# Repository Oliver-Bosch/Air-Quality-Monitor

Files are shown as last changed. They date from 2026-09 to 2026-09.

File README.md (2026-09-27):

# Air-Quality-Monitor

This is a guide to build your own Air-Quality-Monitor (**AQM**). The AQM measures CO2, relative humidity, temperature and particulate matter. The current readings are displayed on a 4-inch TFT screen. The device is connected to the local network via Wi-Fi to synchronise time.

<p align="center">
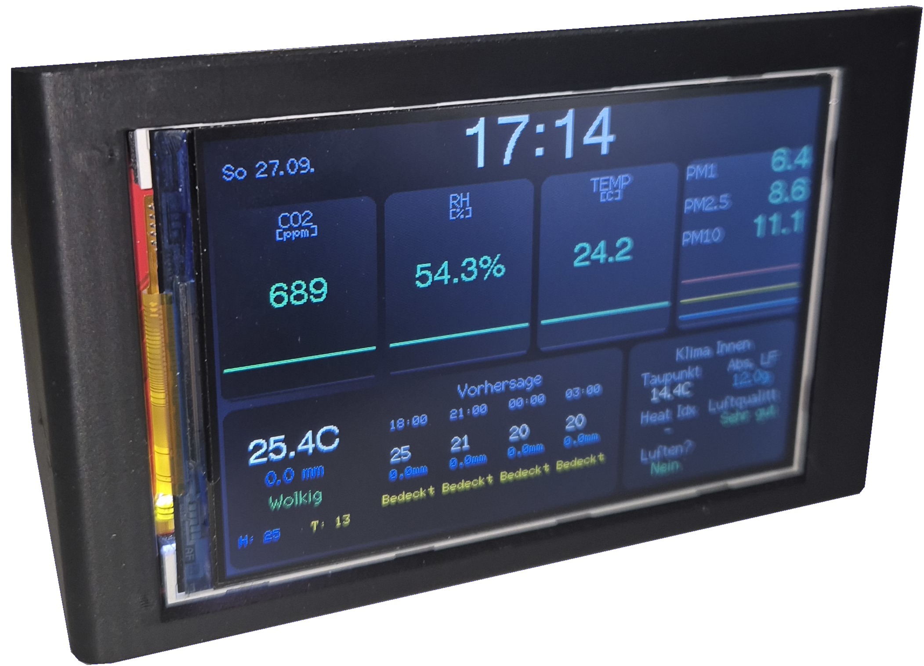
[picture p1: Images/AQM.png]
Image of the AQM
  
</p>

# Table of Contents

- [Parts](#parts)
- [Assembly](#assembly)
- [Installation](#installation)
- [Settings](#settings)
- [Price](#price)
- [Notes](#notes)

# Parts

- ESP32S
- SCD41 CO₂ Sensor
- SHT40 Temperature & Humidity Sensor
- SPS30 Particulate Matter Sensor
- VEML7700 Ambient Light Sensor
- ILI9488 4 Inch TFT Display

# Assembly

To assembel the AQM you should first start with testing all the components on a bredboard which are connected as in figure X. After checking the functinality of all components and printing the body of the case you start by soldering the components to each other as shown in figure Y. Start with screwing the TFT display in place (depending on screw length you have to use washers/springs). After that place the SPS30 in the lower corner with the connector facing the dividing wall of the case. Then you can screw in the SHT40 into its respectiv mounting holes. The SCD41 is mounted using a wedge because of the missing mounting holes. At last step mount the VEML7700 with the pins facing inside and then close the lid of the AQM.

# Installation

After wiring up all components you just need to download the Code and flash it to the ESP32 using the Arduino IDE or similar programms. 

# Settings

All different settings can be changed in the "config.h" file. 

# Price

<div align="center">

| Part | Price |
|---|---|
| ESP32S | 3,42 € |
| SCD41  | 17,99 € |
| SHT40  | 2,79 € |
| SPS30  | 10,45 € |
| VEML7700 | 1,66 € |
| ILI9488 4" TFT Display | 13,52 € |
| **Total** | **49.68 €** |

\* All parts sourced on Aliexpress Mai 2026

<div align="left">

# Notes

Future Home Assistant integration is planned.

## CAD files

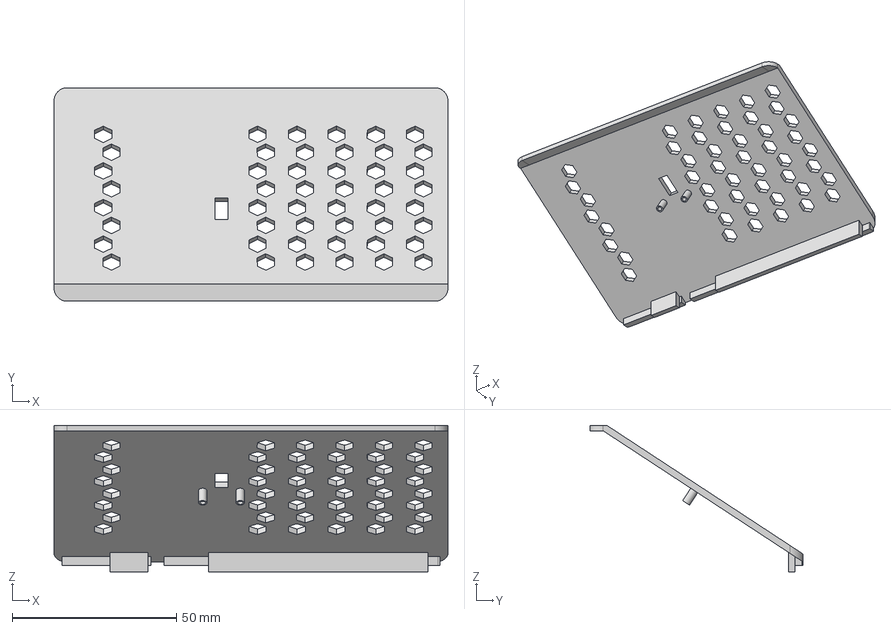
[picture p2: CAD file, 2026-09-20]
Case/Deckel.step
120.0 x 65.0 x 44.7 mm

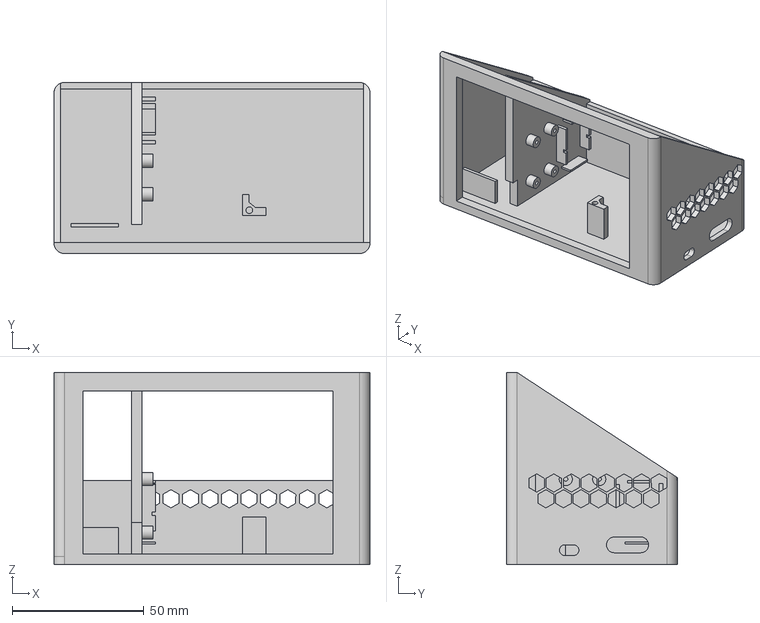
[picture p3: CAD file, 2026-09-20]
Case/AQM CASE.step
120.0 x 65.0 x 73.0 mm

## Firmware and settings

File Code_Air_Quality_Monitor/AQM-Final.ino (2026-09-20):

#include <Arduino.h>
#include <WiFi.h>
#include <WiFiUdp.h>
#include <NTPClient.h>

// Eigene Module
#include "config.h"
#include "wifi_data.h"
#include "daten.h"
#include "sensor.h"
#include "display.h"
#include "espnow.h"
#include "utils.h"
#include "weather.h"

WiFiUDP ntpUDP;
NTPClient timeClient(ntpUDP, "pool.ntp.org", 7200); // UTC+2

SensorDaten aktuelleDaten;

static unsigned long letzteZeitSync = 0;


// ==========================================
// Zeit / Datum formatieren
// ==========================================
void formatTimeAndDate(char* timeBuf, char* dateBuf) {
    unsigned long epoch = timeClient.getEpochTime();

    int h = (epoch % 86400L) / 3600;
    int m = (epoch % 3600) / 60;

    sprintf(timeBuf, "%02d:%02d", h, m);

    const char* daysDE[] = {
        "So", "Mo", "Di", "Mi", "Do", "Fr", "Sa"
    };

    const char* daysEN[] = {
        "Sun", "Mon", "Tue", "Wed", "Thu", "Fri", "Sat"
    };

    int wd = timeClient.getDay();

    const char* dayStr =
        strcmp(LANGUAGE, "GER") == 0
        ? daysDE[wd]
        : daysEN[wd];


    // Datum berechnen
    unsigned long days = epoch / 86400L;

    int year = 1970;

    while (true) {
        bool leap =
            (year % 4 == 0 && year % 100 != 0) ||
            (year % 400 == 0);

        unsigned int diy = leap ? 366 : 365;

        if (days < diy)
            break;

        days -= diy;
        year++;
    }

    int monthDays[] = {
        31, 28, 31, 30, 31, 30,
        31, 31, 30, 31, 30, 31
    };

    if ((year % 4 == 0 && year % 100 != 0) ||
        (year % 400 == 0)) {
        monthDays[1] = 29;
    }

    int month = 0;

    while (days >= (unsigned long)monthDays[month]) {
        days -= monthDays[month];
        month++;
    }

    sprintf(
        dateBuf,
        "%s %02d.%02d.",
        dayStr,
        (int)days + 1,
        month + 1
    );
}


// ==========================================
// WLAN verbinden
// ==========================================
bool verbindeWLAN() {

    if (WiFi.status() == WL_CONNECTED) {
        return true;
    }

    Serial.print("Verbinde mit WLAN");

    WiFi.begin(WIFI_SSID, WIFI_PASS);

    int attempts = 0;

    while (WiFi.status() != WL_CONNECTED &&
           attempts < 30) {

        delay(500);
        Serial.print(".");
        attempts++;
    }

    if (WiFi.status() == WL_CONNECTED) {

        Serial.println();
        Serial.println("WLAN verbunden!");

        Serial.print("IP-Adresse: ");
        Serial.println(WiFi.localIP());

        Serial.print("RSSI: ");
        Serial.print(WiFi.RSSI());
        Serial.println(" dBm");

        return true;
    }

    Serial.println();
    Serial.println("Fehler: WLAN nicht erreichbar.");

    return false;
}


// ==========================================
// NTP synchronisieren
// WLAN bleibt verbunden!
// ==========================================
bool syncZeit() {

    Serial.println("NTP Zeit-Synchronisation...");

    // WLAN sicherstellen
    if (!verbindeWLAN()) {
        Serial.println("NTP abgebrochen: Kein WLAN.");
        return false;
    }

    // NTP initialisieren
    if (!timeClient.isTimeSet()) {
        timeClient.begin();
    }

    // Zeit aktualisieren
    int ntpRetries = 0;

    while (!timeClient.forceUpdate() &&
           ntpRetries < 10) {

        delay(500);

        Serial.print("t");
        ntpRetries++;
    }

    if (ntpRetries < 10) {

        Serial.println();
        Serial.println("Zeit erfolgreich synchronisiert!");

        char timeBuf[10];
        char dateBuf[14];

        formatTimeAndDate(timeBuf, dateBuf);

        Serial.print("Datum: ");
        Serial.println(dateBuf);

        Serial.print("Zeit:  ");
        Serial.println(timeBuf);

        letzteZeitSync = millis();

        return true;
    }

    Serial.println();
    Serial.println("Fehler: NTP Server hat nicht geantwortet.");

    return false;
}


// ==========================================
// SETUP
// ==========================================
void setup() {

    Serial.begin(115200);

    delay(100);

    // ======================================
    // WLAN
    // ======================================

    WiFi.mode(WIFI_STA);

    delay(100);

    Serial.print("MAC Adresse: ");
    Serial.println(WiFi.macAddress());

    // WLAN dauerhaft verbinden
    if (verbindeWLAN()) {

        // NTP direkt synchronisieren
        syncZeit();

    } else {

        Serial.println(
            "WARNUNG: Start ohne WLAN."
        );
    }


    // ======================================
    // LEDs & Backlight
    // ======================================

    pinMode(TFT_BL_PIN, OUTPUT);
    digitalWrite(TFT_BL_PIN, LOW);


    // ======================================
    // Display
    // ======================================

    initDisplay();

    zeichneDashboardRaster();

    Serial.println("Display init");


    // ======================================
    // Sensoren
    // ======================================

    initSensoren();


    // ======================================
    // WLAN bleibt jetzt aktiv!
    // ======================================
}


// ==========================================
// LOOP
// ==========================================
void loop() {

    // ======================================
    // WLAN überwachen
    // ======================================

    if (WiFi.status() != WL_CONNECTED) {

        Serial.println("WLAN Verbindung verloren!");

        verbindeWLAN();
    }


    // ======================================
    // Alle 6 Stunden NTP synchronisieren
    // ======================================

    if (millis() - letzteZeitSync > 21600000UL) {

        syncZeit();
    }


    // ======================================
    // Sensor / Display Update
    // ======================================

    static unsigned long letztesUpdate = 0;

    if (millis() - letztesUpdate > UPDATE_TIME) {

        letztesUpdate = millis();


        // Sensoren lesen
        leseSensoren(aktuelleDaten);


        // ==================================
        // Display Beleuchtung
        // ==================================

        bool istDunkel =
            (aktuelleDaten.lux > LUX_TH_DARK &&
             aktuelleDaten.co2 > 0);

        digitalWrite(
            TFT_BL_PIN,
            istDunkel ? HIGH : LOW
        );


        if (istDunkel) {

            digitalWrite(CO2_AL_LED, LOW);
            digitalWrite(CO2_CR_LED, LOW);
            digitalWrite(RH_LED, LOW);
        }


        // ==================================
        // Uhrzeit / Datum
        // ==================================

        char timeBuf[10];
        char dateBuf[14];

        formatTimeAndDate(
            timeBuf,
            dateBuf
        );


        // ==================================
        // Top Bar
        // WLAN bleibt dauerhaft aktiv
        // ==================================

        updateTopBar(
            dateBuf,
            timeBuf,
            WiFi.status() == WL_CONNECTED
        );


        // ==================================
        // Sensordaten
        // ==================================

        updateSensorKacheln(
            aktuelleDaten
        );


        updateUntererBereich(
            aktuelleDaten
        );


        // ==================================
        // LEDs
        // ==================================

        if (!istDunkel) {

            updateLEDs(
                aktuelleDaten
            );
        }
    }


    delay(10);
}

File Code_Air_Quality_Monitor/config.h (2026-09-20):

#pragma once

// =====================
// Settings
// =====================
#define LANGUAGE        "GER"               // "GER" for german or "ENG" for english
#define LED_ALERTS      true                // CO2 & RH Alert LEDs active
#define ORIENTATION     3                   // 0: Vertikal, 1: Horizontal
#define UPDATE_TIME     500                 // time in ms between measurements
#define h_AMSL          179                 // Height above mean sea level of the Sensor (only used for weather prediction with AQM-Outdoor-Add-On)  
#define OUTDOOR_TIMEOUT_MS 10000            //
#define HA_SYNCH_TIME   60                  // Time between broadcast of the measurements to Home Assistant in seconds

#define WEATHER_LAT 50.786638
#define WEATHER_LON 6.070075
#define WEATHER_HOURLY_LEN 12

// =====================
// Pins (ESP32)
// =====================
#define SDA_PIN         21
#define SCL_PIN         22

#define CO2_AL_LED      25                  // Alert LED (gelb)
#define CO2_CR_LED      26                  // Critical LED (rot)
#define RH_LED          27                  // Feuchte LED

#define TFT_BL_PIN      17                  // Backlight pin of the TFT display

#define SD_CS_PIN       5                   // Pin for writing the SD card


// =====================
// Threshold values
// =====================

#define LUX_TH_DARK        0.3               // For values below this threshold the screen toggles off

#define CO2_th_alert       1000 
#define CO2_th_critical    1500

#define RH_th_alert_low    35.0             // Zu trockene Luft
#define RH_th_critical     60.0             // Zu feuchte Luft (Schimmelgefahr)
            
#define TEMP_th_alert_low  18.0             // Zu kalt
#define TEMP_th_alert_high 25.0             // Zu warm
#define TEMP_th_critical   28.0             // Hitze

#define pm25_th_alert      15
#define pm25_th_critical   25

#define pm10_th_alert      20 
#define pm10_th_critical   50

#define tvoc_th_alert      300
#define tvoc_th_critical   600

// =====================
// Graphs (Scaling for min & max)
// =====================
#define GRAPH_CO2_MIN      400
#define GRAPH_CO2_MAX      2000

#define GRAPH_RH_MIN       20
#define GRAPH_RH_MAX       80

#define GRAPH_TEMP_MIN     10
#define GRAPH_TEMP_MAX     40

#define GRAPH_PM_MIN       0
#define GRAPH_PM_MAX       50

#define GRAPH_TVOC_MIN     0
#define GRAPH_TVOC_MAX     1000

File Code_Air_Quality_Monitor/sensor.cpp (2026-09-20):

#include "sensor.h"
#include "config.h"
#include <Wire.h>
#include <SensirionI2cScd4x.h>
#include <SensirionI2cSht4x.h>
#include <SensirionI2cSps30.h>
#include <Adafruit_VEML7700.h>
#include <cmath>
#include "utils.h"

#ifdef NO_ERROR
#undef NO_ERROR
#endif
#define NO_ERROR 0
static bool first = true;
const float alpha = 0.3f;

// ==========================================
// SENSOR-OBJEKTE
// ==========================================
SensirionI2cScd4x scd4x;
SensirionI2cSht4x sht4x;
SensirionI2cSps30 sps30;
Adafruit_VEML7700 veml = Adafruit_VEML7700();

static bool vemlOK = false;
static bool sps30OK = false;


// ==========================================
// INITIALISIERUNG ALLER SENSOREN
// ==========================================
void initSensoren() {
    Wire.begin(SDA_PIN, SCL_PIN);
    delay(100);

    // 1. SCD41 (CO2)
    scd4x.begin(Wire, SCD41_I2C_ADDR_62);
    scd4x.wakeUp();
    scd4x.stopPeriodicMeasurement();
    scd4x.reinit();
    if (scd4x.startPeriodicMeasurement() != 0) {
        Serial.println("SCD41 Start Fehler!");
    } else {
        Serial.println("SCD41 OK");
    }

    // 2. SHT40 (Temp & Feuchte)
    sht4x.begin(Wire, SHT40_I2C_ADDR_44);
    Serial.println("SHT40 OK");

    // 3. SPS30 (Feinstaub)
    sps30.begin(Wire, SPS30_I2C_ADDR_69);
    sps30.stopMeasurement();
    delay(50);
    int16_t err = sps30.startMeasurement(SPS30_OUTPUT_FORMAT_OUTPUT_FORMAT_FLOAT);
    if (err != NO_ERROR) {
        Serial.println("SPS30 Start Fehler!");
        sps30OK = false;
    } else {
        Serial.println("SPS30 OK");
        sps30OK = true;
    }

    Wire.end();
    delay(50);
    Wire.begin(SDA_PIN, SCL_PIN);
    delay(100);

    vemlOK = veml.begin();
    if (!vemlOK) {
        Serial.println("VEML7700 nicht gefunden - Lux deaktiviert");
    } else {
        veml.setGain(VEML7700_GAIN_1);
        veml.setIntegrationTime(VEML7700_IT_100MS);
        Serial.println("VEML7700 OK");
    }
}

// ==========================================
// SENSOREN AUSLESEN UND INS PAKET PACKEN
// ==========================================

bool leseSensoren(SensorDaten &daten) {
    // SHT40, SPS30, VEML immer lesen
    sht4x.measureHighPrecision(daten.tempSht, daten.humSht);
    daten.dewPoint    = calcDewPoint(daten.tempSht, daten.humSht);
    daten.absHumidity = calcAbsHumidity(daten.tempSht, daten.humSht);
    daten.lux = vemlOK ? veml.readLux(VEML_LUX_AUTO) : 100.0f;
    // SPS30 ...

    if (sps30OK) {
    uint16_t dataReadyFlag = 0;
    sps30.readDataReadyFlag(dataReadyFlag);
    if (dataReadyFlag) {
        float mc1p0 = 0, mc2p5 = 0, mc4p0 = 0, mc10p0 = 0;
        float nc0p5 = 0, nc1p0 = 0, nc2p5 = 0, nc4p0 = 0, nc10p0 = 0;
        float typicalParticleSize = 0;
        int16_t err = sps30.readMeasurementValuesFloat(mc1p0, mc2p5, mc4p0, mc10p0,
                                                       nc0p5, nc1p0, nc2p5, nc4p0,
                                                       nc10p0, typicalParticleSize);
        if (err == NO_ERROR) {
            if (first) {
                daten.pm10  = mc1p0;
                daten.pm25  = mc2p5;
                daten.pm100 = mc10p0;
                first = false;
            } else {
                daten.pm10  = alpha * mc1p0  + (1.0f - alpha) * daten.pm10;
                daten.pm25  = alpha * mc2p5  + (1.0f - alpha) * daten.pm25;
                daten.pm100 = alpha * mc10p0 + (1.0f - alpha) * daten.pm100;
            }
        }
    }
}

    // SCD41 nur wenn bereit
    bool dataReady = false;
    scd4x.getDataReadyStatus(dataReady);
    if (dataReady) {
        scd4x.readMeasurement(daten.co2, daten.tempScd, daten.humScd);
    }

    Serial.println("==========Messwerte=============");
    Serial.print("Lux: ");    Serial.println(daten.lux);
    Serial.print("PM1.0: ");  Serial.println(daten.pm10);
    Serial.print("PM2.5: ");  Serial.println(daten.pm25);
    Serial.print("PM10: ");   Serial.println(daten.pm100);
    Serial.print("CO2: ");    Serial.println(daten.co2);
    Serial.print("Temp: ");   Serial.print(daten.tempSht); Serial.print(" | "); Serial.println(daten.tempScd);
    Serial.print("RH: ");     Serial.print(daten.humSht); Serial.print(" | "); Serial.println(daten.humScd);


    return true; // immer true → Display updated immer
}
